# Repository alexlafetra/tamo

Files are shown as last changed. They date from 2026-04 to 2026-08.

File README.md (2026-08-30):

# Tamo

Tamo is an open source interdisciplinary hardware project designed to be both a piece of jewelry and a small being with (somewhat) complex emotions. This repository contains the firmware, hardware design (PCB & 3D files), graphics, and code for the web tools for sprite design and custom creature upload.

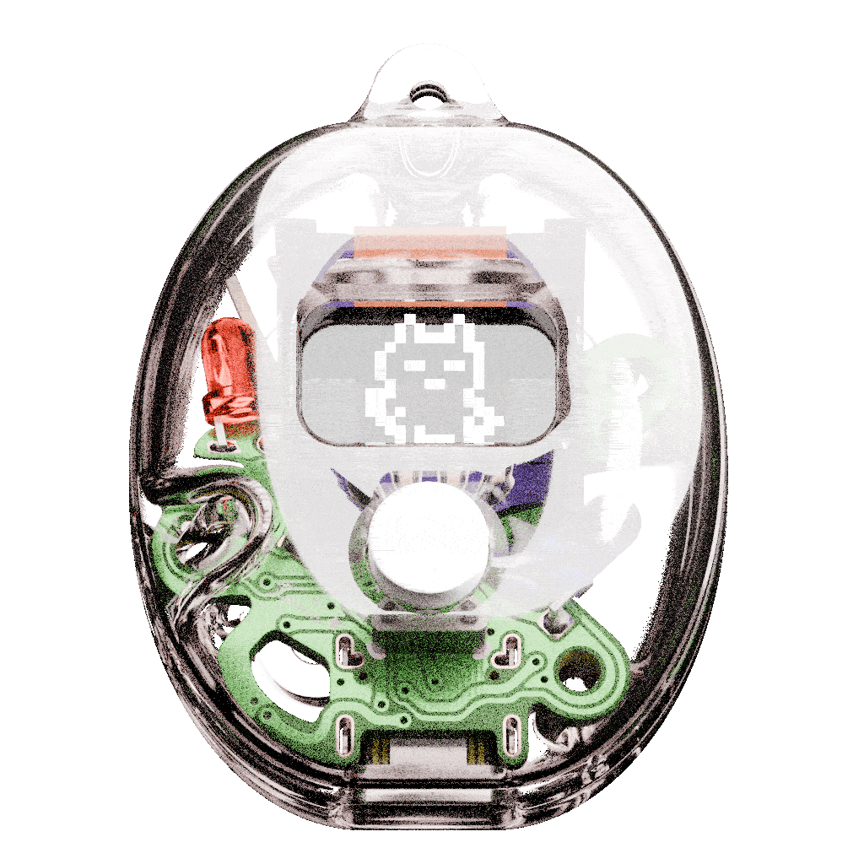
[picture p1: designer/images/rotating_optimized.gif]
gif of tamo rotating


### Background

This project started as a way of making something that could be shared between people in my life that felt precious, but also mass-produced. It's designed to feel like it has an independent existence outside of just being your pet, like maybe it's "going through some shit," but also like you can effectively comfort it and have a connection to the creature inside Tamo.

### Modes

Tamo supports two modes: the default, "alive" mode and an "animation" mode: 

###### Animation
The animation mode is a very simple video player or slideshow which can loop over up to 16 frames of video at different speeds. It's designed more for tamo as a piece of jewelry, and doesn't feature any interaction other than turning tamo on/off with the main button.

###### Living
Living mode is the default mode for Tamo. While living, Tamo ages, speaks, gets hungry, gets happy, gets sad, gets angry, and eventually dies. Tamo can be afflicted by different maladies: a smoking habit, compulsive eating, mood swings, and depression. Tamo can be fed, talked to, or connected to another Tamo to swap places.

# Sprites
The [custom sprite designer](https://alexlafetra.github.io/tamo/designer.html?sprite) is a tool for creating animations & sprite art for tamo, which can be uploaded to the device using the browser and a USB-C cable.

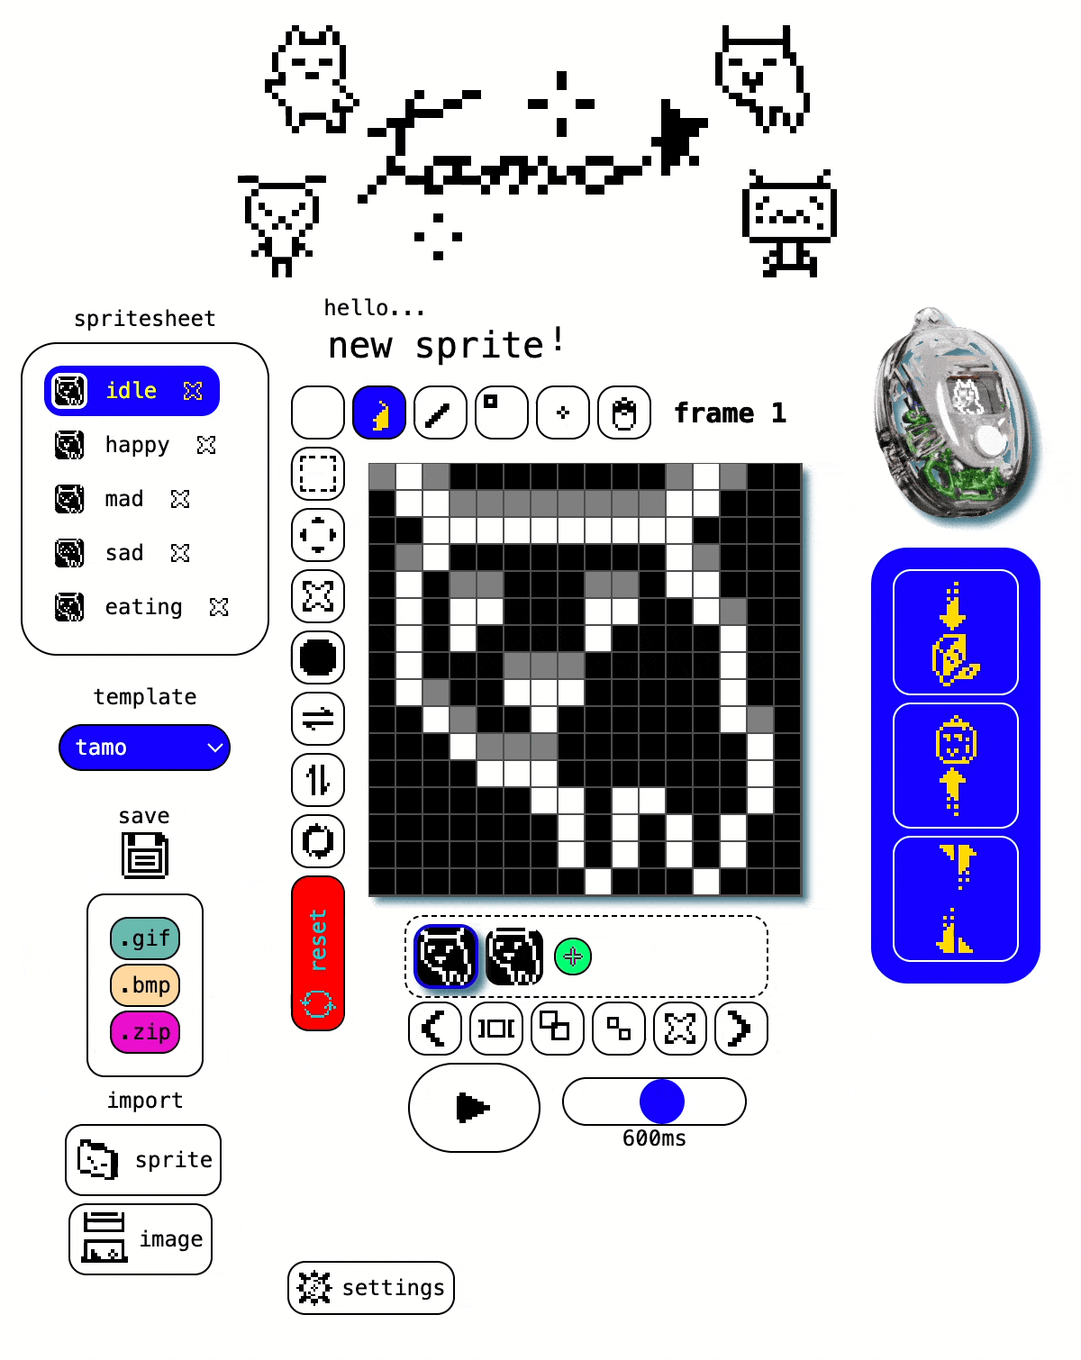
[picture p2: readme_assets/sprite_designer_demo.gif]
screenshot of the designer ui


The mode & creature identity can be set, and new sprites can be flashed to Tamo over USB, using [Tamo's website](https://alexlafetra.github.io/tamo/).

# Firmware

Tamo's firmware is a PlatformIO project built around Spence Konde's [megaTinyCore](https://github.com/SpenceKonde/megaTinyCore) and the Arduino framework, with a modified build process to allow for in-system flash reprogramming. This project uses [PlatformIO](https://platformio.org/) for compiling with a [custom linker script](/tamo/linker/sprites.ld) and to run a few python scripts that upload the EEPROM and custom fuses to the Attiny. Unfortunately, this project hasn't been ported to work as a standalone Arduino project, but this repository contains all the libraries and the platformio.ini file needed to setup the platformIO environment, hopefully making use of the platformIO extension for VSCode almost as beginner-friendly.

During compilation, a python script--`/scripts/compile_spritesheet.py`--automatically converts selected `.bmp` files inside the `/bitmaps` folder to C++ byte arrays and appends them to the main spritesheet array. The creature sprites selected by this script are randomly chosen each time from the 7 default creatures, so each tamo gets a different mix of sprite artwork to start with. Each of these creatures can be overwritten later, though.

A second script--`/scripts/build_eeprom.py`--builds a binary file with the default EEPROM values and writes it to the Attiny3217's EEPROM memory after the firmware upload.

## Uploading firmware

The Attiny3217 firmware is uploaded via its UPDI interface, which is exposed on the motherboard as three header pins (UPDI,GND, and VCC). For development, I've been using [pymcuprog](https://pypi.org/project/pymcuprog/) and this [Pico UART Bridge](https://github.com/Noltari/pico-uart-bridge) design to use a Pi Pico as a UPDI programmer and upload code to the Attiny. Any USB UPDI programmer should work, though!

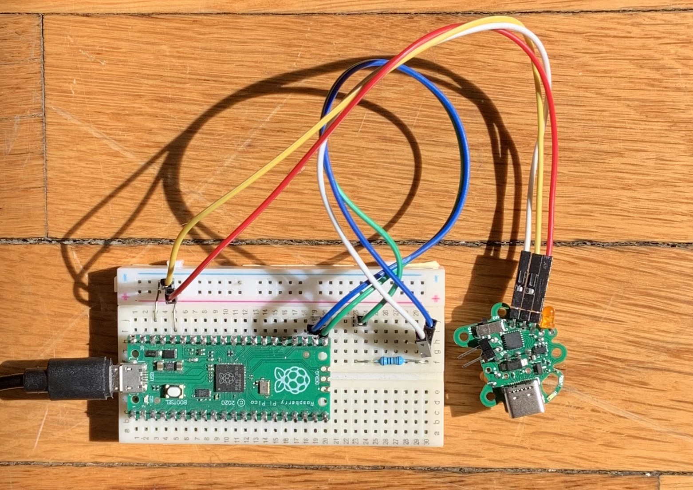
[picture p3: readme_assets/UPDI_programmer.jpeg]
Image of Tamo with UPDI programmer

###### Example of the Pico UART Bridge wired to the Tamo board's UPDI header pins as a programmer.

Although the UPDI headers are exposed on the board, the `SBU1/SBU2` pins on Tamo's USB-C jack are also both tied to the UPDI pin on the Attiny so the chip can be programmed using just a USB cable plugged into the USB-C port with the other end specially wired to a UPDI programmer. You'll need to make sure whatever cable you use for this carries the `SBU1/SBU2` lines, but this allows programming Tamo from inside its shell.

### A note about custom fuses & overwriteable flash

The Attiny has strict rules about which sections of flash memory can overwrite other sections -- code running in `BOOT` can overwrite `APPCODE` and `APPDATA` sections, but `BOOT` can never be overwritten (even by other code running from `BOOT`). By default, the *entire* memory of the Attiny is designated as the `BOOT` section, meaning the code uploaded to flash doesn't have permission to rewrite any part of the Attiny's memory.

So, to overwrite bitmap data during runtime (allowing the firmware to overwrite new artwork in the Attiny's flash without recompiling the firmware with new sprites) we need to ask the Attiny3217 to store the bitmap data in a section of its memory demarcated as `APPCODE` while still running the main code from the `BOOT` section. This just requires three things:

1. Creating a linker script which places the `spritesheet` variable containing all the bitmap data at a fixed memory address. This linker script is a copy of the default TinyMegaCore linker script, with a special section titled ".bitmap_data" added which has a specific, fixed address. 

2. The "spritesheet" variable in our C++ code needs a little linker flag to tell the linker to place it in that new ".bitmap_data" section:

```
const unsigned char spritesheet[]  __attribute__((section(".bitmap_data"))) = {
    ... DATA ...
};

```

2. Finally, the `BOOTEND` and `APPEND` fuses on the Attiny3217 need to be set during upload so that the `BOOT`/`APPCODE` partition is created, at the specific address of .bitmap_data, so that the .bitmap_data section is placed in `APPCODE`.

The addresses are written as `[APPEND page address, BOOTEND page address]` (the addresses values are actually the 256-byte *page* address, ie. 0x01 is byte 256, 0x02 is byte 512 etc.) For tamo, the `BOOTEND` fuse is set to `0x5E = 94`, meaning `94 x 256B = 24,064B` of flash is reserved for the main firmware running in `BOOT`, and the remaining ~8kB are used for bitmaps. The `APPEND` fuse is set to `0x00`, which tells the Attiny3217 to allocate the rest of flash from `BOOTEND` onwards for the `APPCODE` section.

To set these fuses using `pymcuprog`, run:

```
pymcuprog write --tool uart --device attiny3217 --uart {USB DEVICE PORT} --clk 230400 --memory fuses --offset 7 --literal 0x00 0x5E 
```
###### On Mac: The USB device will be something like ```/dev/cu.usbmodem14101```. Run ```ls /dev/tty.*``` in a terminal window to get a list of connected USB devices.

To read back the fuse values and check if they were written correctly, run:

```
pymcuprog read --tool uart --device attiny3217 --uart {USB DEVICE PORT} --clk 230400 --memory fuses
```

## Thank you's

This project is built with support from these other projects:

- [pymcuprog](https://pypi.org/project/pymcuprog/), for uploading and writing fuses via UPDI

- This [Pico UART Bridge](https://github.com/Noltari/pico-uart-bridge) project for building a custom UPDI programmer, so helpful!

- The code for the display was originally based on Datacute's [SSD1306 OLED Library](https://github.com/datacute/Tiny4kOLED), although now very heavily augmented

- The PCBs for this project were designed in [KiCad](https://www.kicad.org/) and specifically the battery charging schematic is based on the schematic for Adafruit's [MicroLipo Battery Charger](https://github.com/adafruit/Adafruit-MicroLipo-PCB)

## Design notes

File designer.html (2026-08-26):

v1.0.0

tamo sprite designer

[ pixel editing ]

+ [shift] - toggle color

+ p - pixel

+ l - line

+ r - rectangle

+ c - circle

+ f - fill

[ frame editing ]

+ s - select

+ m - move

[ misc. ]

+ [space] - play/pause

+ [ < / > ] - change frame

+ [ ^ / v ] - change sprite

canvas

grid

overlay

*

resize

-- zoom --

 settings

download spritesheet

{Y}

automatically create sprites

resize canvas to images

show debug transmission buttons

show canvas settings

--foreground--

white

black

transparent

--background--

white

black

transparent

copy

image





dither:







brightness:

resize to fit:

width

height

center

save



.gif

.bmp

.zip

import



sprite



image











animation



--speed--

1fps

--sleep--

5min

--blink--

off

spritesheet

template

hello...

new sprite

!















600ms















pixel















 reset

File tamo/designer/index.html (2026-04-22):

    



frame -- 1 / 1













undo

redo

pixel













invert







settings

x

frame delay

zoom

hide grid

disable overlay

sprites:

template:

 upload

export to tamo

save...

.zip

.gif

name:

tamo

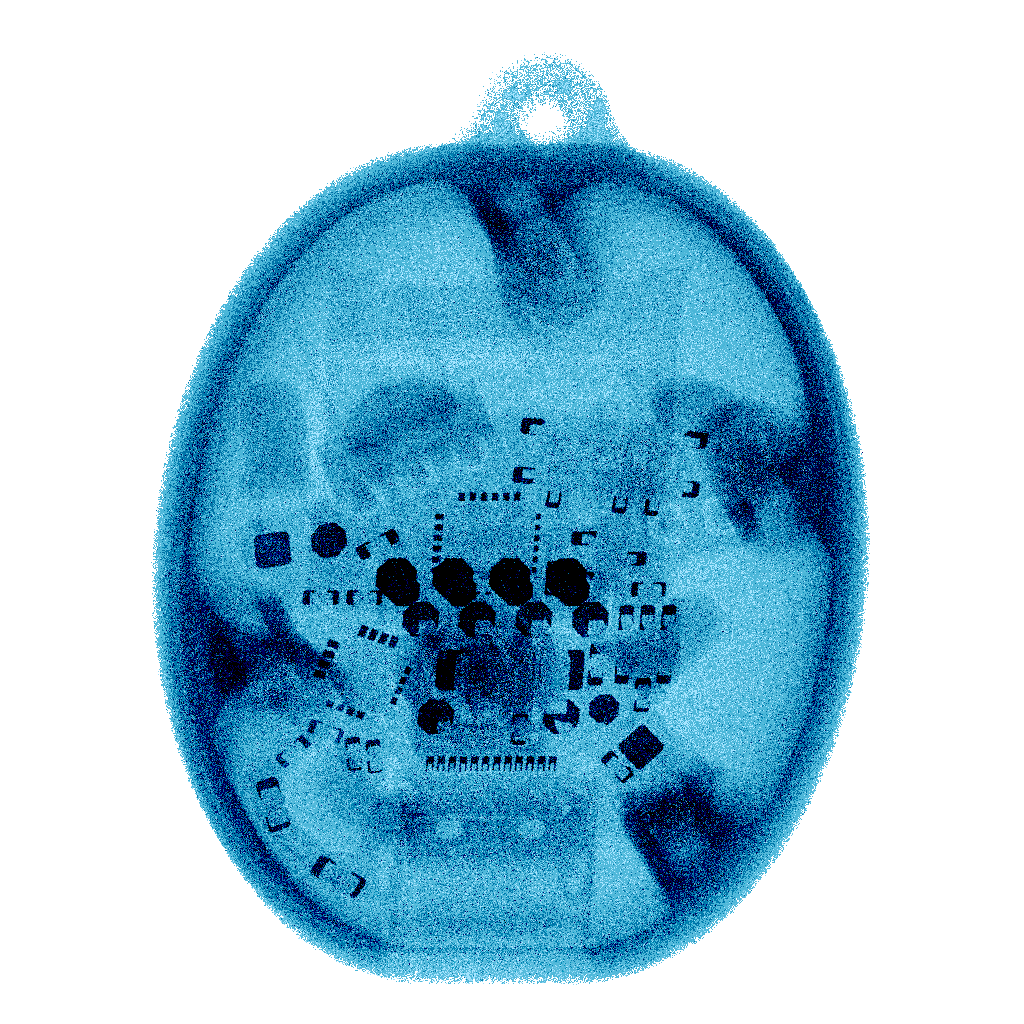
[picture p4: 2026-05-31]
designer/images/combined_optimized.gif

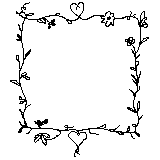
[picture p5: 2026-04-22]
designer/images/border_animated.gif

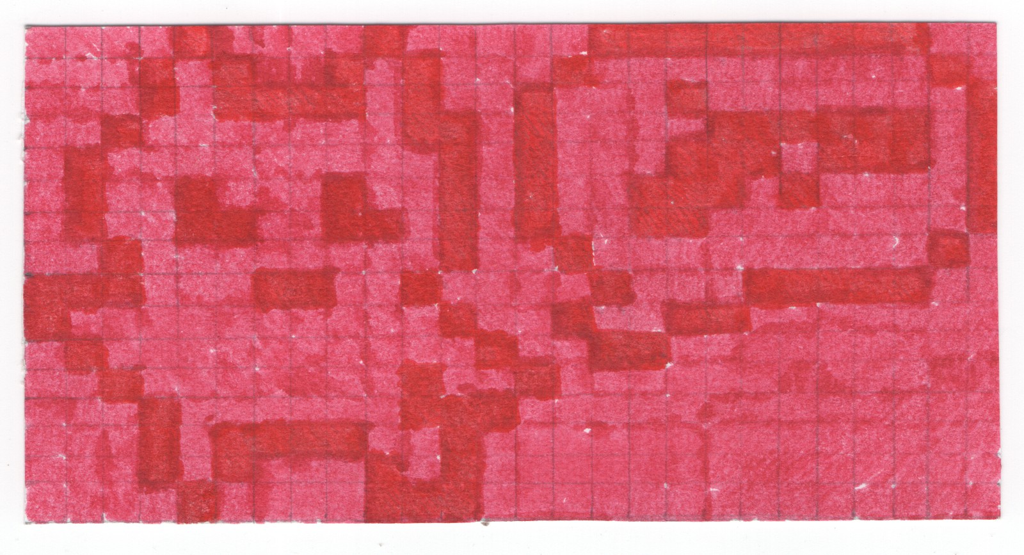
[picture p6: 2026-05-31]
designer/images/tamo_drawing.jpg

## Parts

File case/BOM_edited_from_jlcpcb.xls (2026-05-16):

JLCPCB BOM Tool - BOM Matching
BOM name：bom-JLCPCB Assembly Order.xlsx |  |  | Download Time：2026-02-26 04:10:01 |  |  |  | * Our matching results are updated in real-time, but stock and prices may change. If it's been over 24 hours, please re-match before placing your order.
PCB Assembled Qty：5 |  |  | Est. Total Price：18.4623
Your BOM |  |  |  |  | Matched Parts |  |  |  |  |  |  | Order Information
Top Designator | Bottom Designator | Comment | Footprint | JLCPCB Part # | Matches | Part # | Manufacturer | Footprint | Description | Category | Warning | JLCPCB Part # | Product link | Lib Type | Qty | Source | Total Price ($)
 | C2,C1 | 10碌F | C_0402_1005Metric |  | Select by System | CL05A106MQ5NUNC | Samsung Electro-Mechanics | 0402 | 10uF 6.3V X5R ±20% 0402 Multilayer Ceramic Capacitors MLCC - SMD/SMT ROHS | Multilayer Ceramic Capacitors MLCC - SMD/SMT |  | C15525 | https://jlcpcb.com/partdetail/16204-CL05A106MQ5NUNC/C15525 | Basic | 10 | 10 JLCPCB | 0.056
 | D3 | LED | LED_0603_1608Metric |  | Select by System | KT-0603R | Hubei KENTO Elec | 0603 | -40℃~+85℃ 120° 2.4V 20mA 300mcd 40mW 615nm~630nm 645nm Discrete Diode Red Water Clear 0603 LED Indication - Discrete ROHS | LED Indication - Discrete |  | C2286 | https://jlcpcb.com/partdetail/Hubei_KENTOElec-KT0603R/C2286 | Basic | 5 | 5 JLCPCB | 0.0325
 | D4 | LED | LED_0603_1608Metric |  | Select by System | KT-0603W | Hubei KENTO Elec | 0603 | 100mW 120° 2.6V~3.1V 360mcd 5mA Discrete Diode Top-mount White Yellow Lens 0603 LED Indication - Discrete ROHS | LED Indication - Discrete |  | C2290 | https://jlcpcb.com/partdetail/Hubei_KENTOElec-KT0603W/C2290 | Basic | 5 | 5 JLCPCB | 0.059
 | D5 | SS14 | D_SMA |  | Select by System | SS14 | MDD(Microdiode Semiconductor) | SMA(DO-214AC) | -55℃~+150℃ 1A 25A 300uA@40V 40V 550mV@1A Independent SMA(DO-214AC) Schottky Diodes ROHS | Schottky Diodes |  | C2480 | https://jlcpcb.com/partdetail/MDD_Microdiode_Semiconductor-SS14/C2480 | Basic | 5 | 5 JLCPCB | 0.0825
 | J4 | USB_C_Receptacle | USB_C_Receptacle_24P_TopMnt_Horizontal |  | Select by System | MC-312D-C | SOFNG | SMD | -35℃~+75℃ 1 12V 24P 5A 7.9mm 8,000 times、10,000 cycles Black Female Surface Mount, Right Angle Type-C SMD USB Connectors ROHS | USB Connectors |  | C183607 | https://jlcpcb.com/partdetail/SOFNG-MC_312DC/C183607 | Extended | 5 | 5 JLCPCB | 2.8715
 | Q1 | BSS83P | SOT-23 |  | Select by System | SI2301CDS-T1-GE3 | Vishay Intertech | SOT-23 | -55℃~+150℃ 1 P-Channel 1.6W 10nC@4.5V 142mΩ@2.5V 1V 20V 3.1A 405pF 55pF 75pF P-Channel SOT-23 MOSFETs ROHS | MOSFETs |  | C10487 | https://jlcpcb.com/partdetail/VishayIntertech-SI2301CDS_T1GE3/C10487 | Basic | 5 | 5 JLCPCB | 0.3
 | R2,R3 | 470 | R_0402_1005Metric |  | Select by System | 0402WGF4700TCE | UNI-ROYAL(Uniroyal Elec) | 0402 | -55℃~+155℃ 470Ω 50V 62.5mW Thick Film Resistor ±1% ±100ppm/℃ 0402 Chip Resistor - Surface Mount ROHS | Chip Resistor - Surface Mount |  | C25117 | https://jlcpcb.com/partdetail/25860-0402WGF4700TCE/C25117 | Basic | 10 | 10 JLCPCB | 0.008
 | R5 | 4.7k | R_0402_1005Metric |  | Select by System | 0402WGF4701TCE | UNI-ROYAL(Uniroyal Elec) | 0402 | -55℃~+155℃ 4.7kΩ 50V 62.5mW Thick Film Resistor ±1% ±100ppm/℃ 0402 Chip Resistor - Surface Mount ROHS | Chip Resistor - Surface Mount |  | C25900 | https://jlcpcb.com/partdetail/26643-0402WGF4701TCE/C25900 | Basic | 5 | 5 JLCPCB | 0.004
 | R6 | 10K | R_0402_1005Metric |  | Select by Customer | 0402WGF1002TCE | UNI-ROYAL(Uniroyal Elec) | 0402 | -55℃~+155℃ 10kΩ 50V 62.5mW Thick Film Resistor ±1% ±100ppm/℃ 0402 Chip Resistor - Surface Mount ROHS | Chip Resistor - Surface Mount |  | C25744 | https://jlcpcb.com/partdetail/26487-0402WGF1002TCE/C25744 | Basic | 5 | 5 JLCPCB | 0.004
 | R7 | 33K | R_0402_1005Metric |  | Select by System | 0402WGF3302TCE | UNI-ROYAL(Uniroyal Elec) | 0402 | -55℃~+155℃ 33kΩ 50V 62.5mW Thick Film Resistor ±1% ±100ppm/℃ 0402 Chip Resistor - Surface Mount ROHS | Chip Resistor - Surface Mount |  | C25779 | https://jlcpcb.com/partdetail/26522-0402WGF3302TCE/C25779 | Basic | 5 | 5 JLCPCB | 0.004
 | R1A1,R2A1,R1,R4 | 5.1K | R_0402_1005Metric |  | Select by Customer | 0402WGF5101TCE | UNI-ROYAL(Uniroyal Elec) | 0402 | -55℃~+155℃ 5.1kΩ 50V 62.5mW Thick Film Resistor ±1% ±100ppm/℃ 0402 Chip Resistor - Surface Mount ROHS | Chip Resistor - Surface Mount | 1.There may be multiple types of parts, but one type of part has been matched. Please check.; | C25905 | https://jlcpcb.com/partdetail/26648-0402WGF5101TCE/C25905 | Basic | 20 | 20 JLCPCB | 0.016
 | U3 | ~ | SMD,8x2.8mm |  | Select by System | MSK12C02-HB | SHOU HAN | SMD,8x2.8mm | -25℃~+70℃ 1.4mm 10,000 Cycles 12V 2.8mm 50mA 8mm Black Rectangular Columnar SMD(SMT) Tab SPDT Surface Mount, Right Angle SMD,8x2.8mm Slide Switches ROHS | Slide Switches |  | C431541 | https://jlcpcb.com/partdetail/SHOUHAN-MSK12C02HB/C431541 | Extended | 6 | 6 JLCPCB | 0.3678
 | U4 | MCP73831T-2ACI/OT | SOT-23-5 |  | Select by System | MCP73831T-2ACI/OT | Microchip Tech | SOT-23-5 | -40℃~+85℃ 1 3.75V~6V 4.2V 53uA 550mA Charging IC Lithium Battery SOT-23-5 Battery Management ROHS | Battery Management |  | C424093 | https://jlcpcb.com/partdetail/MicrochipTech-MCP73831T_2ACIOT/C424093 | Extended | 5 | 5 JLCPCB | 3.6645
 | U6 | ATtiny3217-M | QFN-24-1EP_4x4mm_P0.5mm_EP2.6x2.6mm |  | Select by System | ATTINY3217-MNR | Microchip Tech | WQFN-24-EP(4x4) | -40℃~+105℃ 1.8V~5.5V 10bit 20MHz 22 256Byte 2KB 32KB 8 Bit 8bit AVR Built-in FLASH WQFN-24-EP(4x4) Microcontrollers (MCU/MPU/SOC) ROHS | Microcontrollers (MCU/MPU/SOC) |  | C614177 | https://jlcpcb.com/partdetail/MicrochipTech-ATTINY3217MNR/C614177 | Extended | 5 | 5 JLCPCB | 10.9925

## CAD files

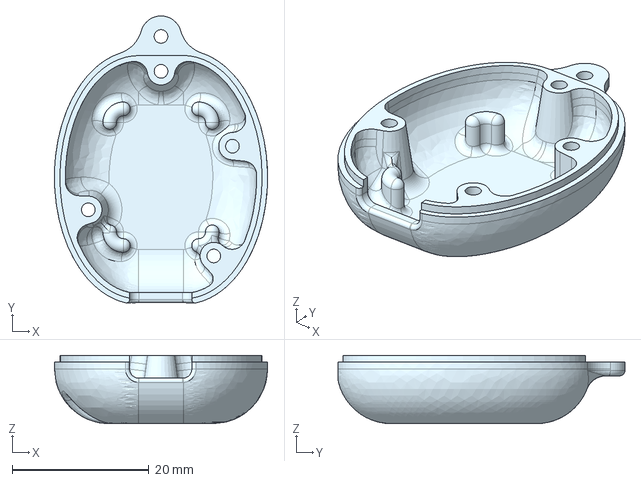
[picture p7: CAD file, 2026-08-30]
case/bottom.step
31.2 x 42.0 x 10.0 mm

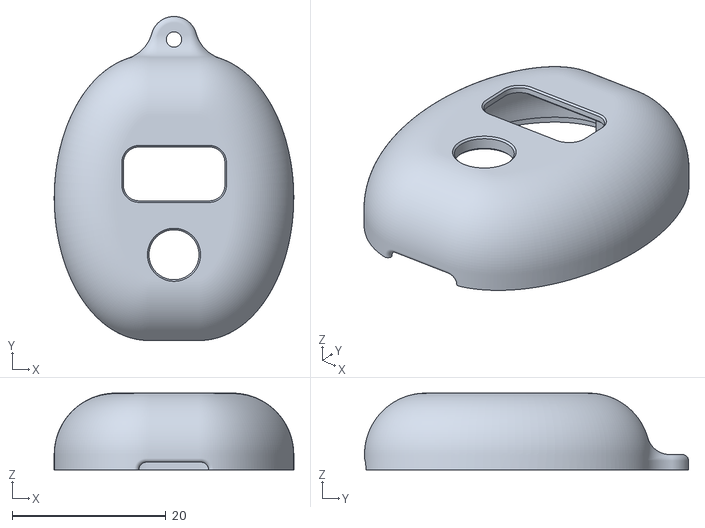
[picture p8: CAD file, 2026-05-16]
case/top.stl
31.2 x 42.2 x 10.0

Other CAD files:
case/TOP_SHELL_12.23.25.stl

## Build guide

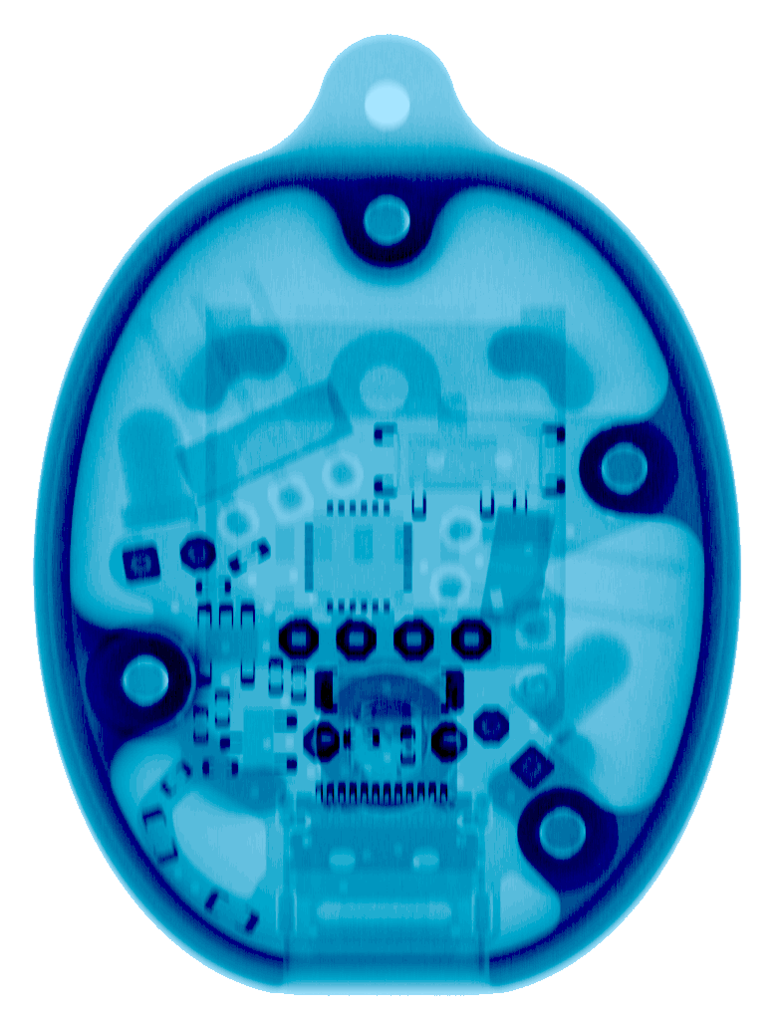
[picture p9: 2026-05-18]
manual/images/xray_alpha.png

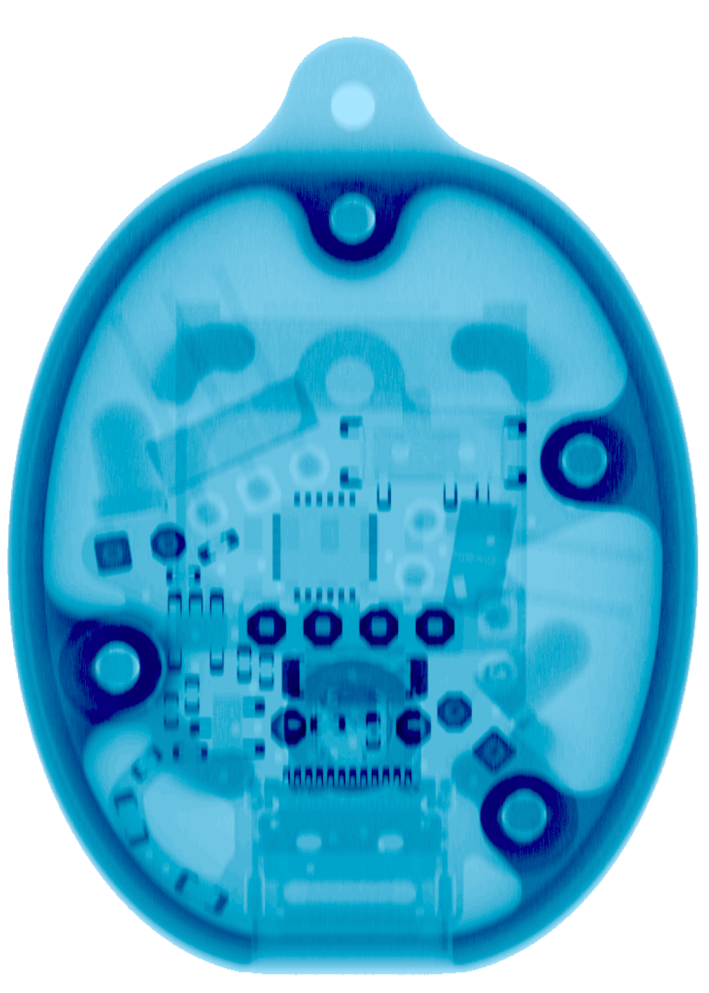
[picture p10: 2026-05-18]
manual/images/xray.png

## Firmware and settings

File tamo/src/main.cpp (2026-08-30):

//https://github.com/Lorandil/ATTiny85-optimization-guide?tab=readme-ov-file

//pi pico UART bridge for programming:
//https://github.com/Noltari/pico-uart-bridge

// GPIO16 (Pin 21)	UART0 TX
// GPIO17 (Pin 22)	UART0 RX
// GPIO4 (Pin 6)	UART1 TX
// GPIO5 (Pin 7)	UART1 RX

/*

ok some really convoluded upload stuff:
burning fuses/bootloader needs to be done with UDPI?
CLOCK needs to be 10MHz to communicate with arduino IDE, dunno why

SUPER annoying highkey annoying vibes
 --> flashing fuses/initial upload needs to use UPDI friend (dunno why it won't work with pi pico)
 --> Subsequent UART uploads need to be done within 8s of a power cycle, which means plug/unplug attiny (or connect a lil button)
 ^^THIS is important for the new board designs, bc the user shouldn't have to power cycle the board!
 ==> Test w the 1sec timeout and see if that works. Figure out how to "Reset"/power cycle Attiny via the USB-->UART bridge
 ^^Actually, i guess this isn't important for the board design since you don't need to "enter bootloader" unless you're actually
 uploading new code, at which point yeah you'll need to reset the tamo
*/


#define BUTTON_PIN PIN_PA2
#define LED_1 PIN_PA6
#define LED_0 PIN_PC0
#define UART_RX_PIN PIN_PB3
#define UART_TX_PIN PIN_PB2


/*
notes on pins:

PA7 -- Battery vcc

PB0 -- screen SCL
PB1 -- screen SDA

PB2 -- UART TX
PB3 -- UART RX

PA6 -- DAC out / LED A
PC0 -- LED B
*/

using namespace std;

#include <EEPROM.h>
#include "utils.h"
#include "communication.h"
#include "spritesheet.h"

//this stores the active graphics area! which is half-res of the screen, sprites are drawn 2x
#include "FrameBuffer.h"
// FrameBuffer fbo(36,24);

#include <Wire.h>
#include "Display.h"
SSD1306Device oled;

#include "Tamo.h"
Tamo tamo;

// FrameBuffer fbo(72,48);
// FrameBuffer fbo(36,24);
/*
the attiny3217 can't store a full 64x32 buffer in RAM, so instead
you store a half-buffer, which is good enough for almost everything
except full-screen slideshow images.
These need to be split into two 64x16 chunks
*/
FrameBuffer fbo(32,32);



//Interrupt callback to wake Attiny back up
ISR(PORTA_PORT_vect) {
  PORTA.INTFLAGS = PIN2_bm; // Clear interrupt flag for PIN 2
  tamo.setStatusBit(IS_ASLEEP_BIT,false);
}

//RTC 'body()' timer interrupt to update tamo's health/state
//taken from: https://github.com/SpenceKonde/megaTinyCore/blob/master/megaavr/extras/PowerSave.md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
ISR(RTC_PIT_vect)
{
  RTC.PITINTFLAGS = RTC_PI_bm;          /* Clear interrupt flag by writing '1' (required) */
  tamo.body();
}

//initialize RTC
//also taken from: https://github.com/SpenceKonde/megaTinyCore/blob/master/megaavr/extras/PowerSave.md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
void RTC_init(void)
{
  /* Initialize RTC: */
  while (RTC.STATUS > 0)
  {
    ;                                   /* Wait for all register to be synchronized */
  }
  RTC.CLKSEL = RTC_CLKSEL_INT32K_gc;    /* 32.768kHz Internal Ultra-Low-Power Oscillator (OSCULP32K) */

  RTC.PITINTCTRL = RTC_PI_bm;           /* PIT Interrupt: enabled */

  // RTC.PITCTRLA = RTC_PERIOD_CYC16384_gc /* RTC Clock Cycles 16384, resulting in 32.768kHz/16384 = 2Hz */
  RTC.PITCTRLA = RTC_PERIOD_CYC32768_gc /* RTC Clock Cycles 16384, resulting in 32.768kHz/16384 = 2Hz */
  | RTC_PITEN_bm;                       /* Enable PIT counter: enabled */
}

//important to do so you save power on sleep()
void disconnectUnusedPins(){
  const uint8_t unused_pins[] = {
    //updi pin, doesn't need to be disconnected
    // PIN_PA0,
    PIN_PA1,
    // PIN_PA2, //Button
    PIN_PA3,
    PIN_PA4,
    PIN_PA5,
    // PIN_PA6, //LED A
    PIN_PA7,
    // PIN_PB0, //SCL
    // PIN_PB1, //SDA
    // PIN_PB2, //RX
    // PIN_PB3, //TX
    PIN_PB4,
    PIN_PB5,
    PIN_PB6,
    PIN_PB7,
    // PIN_PC0, //LED B
    PIN_PC1,
    PIN_PC2,
    PIN_PC3,
    PIN_PC4,
    PIN_PC5
  };
  for(uint8_t i = 0; i<sizeof(unused_pins); i++){
    pinMode(unused_pins[i],OUTPUT);
  }
}

//trying to set the IVSEL register, so the vectors are placed in BOOT instead of APPCODE
//which happens automatically when BOOT isn't 0x00
//src: https://www.microchip.com/content/dam/mchp/documents/OTH/ApplicationNotes/ApplicationNotes/AN1983WritingtoFlashandEEPROMonthetinyAVR1-series40001983A.pdf
//sec 2.2
void onBeforeInit(){
  CCP = CCP_IOREG_gc;           // unlock protected register, 4-cycle window
  CPUINT.CTRLA = CPUINT_IVSEL_bm; // set IVSEL=1: vectors at start of BOOT (0x0000)
}

void setup(){

  //connect pins to leds, button
  pinMode(LED_1,OUTPUT);
  pinMode(LED_0,OUTPUT);
  pinMode(BUTTON_PIN,INPUT_PULLUP);

  //set floating pins to OUTPUT (to save power during sleep)
  disconnectUnusedPins();

  //this sleep mode only leaves the RTC running, and it's the one that saves the most energy
  set_sleep_mode(SLEEP_MODE_PWR_DOWN);
  
  //allows the CPU to go to sleep
  sleep_enable();

  // Enable global interrupts
  sei();

  //turn on RTC timer
  RTC_init();

  //turn on/set up the screen
  oled.begin(72, 40);
  
  //initialize UART
  Serial.begin(115200);

  tamo.init();
}

void loop() {
  // tamo.qrCode();
  switch(tamo.mode){
    default:
    case NORMAL_TAMO:
      tamo.live();
      break;
    case SLIDESHOW:
      tamo.slideshow();
      break;
  }
}

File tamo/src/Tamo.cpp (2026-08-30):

#include "Arduino.h"
#include "Sprite.h"
#include "Tamo.h"
#include "utils.h"
#include "Display.h"
#include "spriteFrames.h"
#include "communication.h"
#include <EEPROM.h>

Tamo::Tamo(){
  sprite = Sprite(SPRITESTARTX,SPRITESTARTY,16,16,getSprite(IDLE_SPRITE),2,MEDIUM);
}

void Tamo::init(){
  mode = TAMO_MODE(EEPROM.read(EEPROM_MODE_ADDR));
  identity = SPRITE_IDENTITY(EEPROM.read(EEPROM_IDENTITY_ADDR));
  health = uint16_t(EEPROM.read(EEPROM_HEALTH_ADDR_MSB))<<8 | uint16_t(EEPROM.read(EEPROM_HEALTH_ADDR_LSB));
  // status = EEPROM.read(EEPROM_STATUS_ADDR); //this is causing weird problems with sleep, smoking on reboot
  setStatusBit(NEEDS_TO_SMOKE_BIT,false);
}

bool Tamo::getStatusBit(uint8_t which){
  return 1&(status>>which);
}

void Tamo::setStatusBit(uint8_t which, bool state){
  if(state){
    status |= (1<<which);
  } 
  else{
    status &= ~(1<<which);
  }
}

void Tamo::sleepCheck(){
  setStatusBit(IS_ASLEEP_BIT,itsbeen(TIME_BEFORE_SLEEP));
}

void Tamo::sleep(){

  //set tamo into sleep mode
  setStatusBit(IS_ASLEEP_BIT,true);

  //when the RTC interrupt finishes it goes to this line and tamo can go back to sleep
  while(isAsleep()){
    // digitalWrite(LED_1,CHANGE);
    //put the attiny to sleep
    sleepHardware();
  }

  wakeHardware();
}

void Tamo::setIdentity(SPRITE_IDENTITY i){
  EEPROM.update(EEPROM_IDENTITY_ADDR,i);
  identity = i;
  setMoodSprite();
}

const uint16_t * Tamo::getSprite(uint8_t whichSprite){
  return creature_sprites[identity][whichSprite];
  // switch(identity){
  //   case TAMO:
  //     return tamo_spritesheet[whichSprite];
  //   case PORCINI:
  //     return porcini_spritesheet[whichSprite];
  //   case BUG:
  //     return bug_spritesheet[whichSprite];
  //   case BOTO:
  //     return boto_spritesheet[whichSprite];
  //   case CUSTOM_SPRITE:
  //     return custom_spritesheet[whichSprite];
  //   default:
  //     return tamo_spritesheet[whichSprite];
  // }
}

void Tamo::slideshow(){

  //preset speeds/sleep times (0 sleep time is infinite)
  const uint16_t slideshow_speeds[] = {0,100,500,1000,2000,5000,10000,60000};
  const uint32_t slideshow_sleep_times[] = {0,10000,60000,300000};

  uint8_t slideshow_framecount = EEPROM.read(EEPROM_SLIDESHOW_FRAME_COUNT_ADDR);
  uint16_t slideshow_speed = slideshow_speeds[EEPROM.read(EEPROM_SLIDESHOW_SPEED_ADDR)];
  uint32_t slideshow_sleeptime = slideshow_sleep_times[EEPROM.read(EEPROM_SLIDESHOW_SLEEP_TIME_ADDR)];
  uint16_t slideshow_blink_interval = EEPROM.read(EEPROM_SLIDESHOW_BLINK_TIME_ADDR);
  
  if(slideshow_blink_interval == 0)
    oled.disableFadeOutAndBlinking();
  else
    oled.blink(slideshow_blink_interval-1);

  uint32_t timeOfLastFrame = 0;
  uint8_t counter = 0;

  //offset LEDs so they're opposite
  digitalWrite(LED_1,LOW);
  digitalWrite(LED_0,HIGH);

  LONG_PRESS = false;
  lastTime = millis();

  while(true){
    timeOfLastFrame = millis();
    oled.bitmap_from_spritesheet(4,0,64,32,slideshow_frame_0+counter*256);

    counter = (counter+1)%slideshow_framecount;

    //if the speed is slow, change LEDs on each frame
    if(slideshow_speed > 100){
      digitalWrite(LED_1,CHANGE);
      digitalWrite(LED_0,CHANGE);
    }
    //if it's fast, change LEDs when frames wrap around
    else if(counter == 0){
      digitalWrite(LED_1,CHANGE);
      digitalWrite(LED_0,CHANGE);
    }

    do{
      checkInput(false);
      //the itsbeen(500) call is for debouncing
      if((SINGLE_CLICK && itsbeen(500)) || ((slideshow_sleeptime == 0)?false:itsbeen(slideshow_sleeptime))){
        sleep();
        lastTime = millis();
        timeOfLastFrame = millis();
        digitalWrite(LED_1,LOW);
        digitalWrite(LED_0,HIGH);
      }
      if(LONG_PRESS && itsbeen(1000)){
        EEPROM.update(EEPROM_MODE_ADDR,NORMAL_TAMO);
        mode = NORMAL_TAMO;
        return;
      }
    }
    while(((millis() - timeOfLastFrame) < slideshow_speed));
  }
}

void Tamo::qrCode(){
  lastTime = millis();
  digitalWrite(LED_1,HIGH);
  digitalWrite(LED_0,LOW);
  uint32_t ledTime = millis();
  oled.clear();
  while(true){
    // oled.bitmap_from_spritesheet(22,0,25,25,qr_code);
    oled.bitmap_from_spritesheet(4,0,25,25,qr_code);
    oled.bitmap_from_spritesheet(41,0,25,25,qr_code);
    if(itsbeen(1000)){
      checkInput(false);
      if(SINGLE_CLICK)
        break;
    }
    if((millis() - ledTime) > 1000){
      digitalWrite(LED_1,CHANGE);
      digitalWrite(LED_0,CHANGE);
      ledTime = millis();
    }
  }
  oled.clear();
  digitalWrite(LED_1,LOW);
  digitalWrite(LED_0,LOW);
  mood = MOOD_RANDOM;
}

bool Tamo::isFeeling(){
  //if there's still time on the moodTime counter, or if there's not but the next frame isn't yet, keep animating
  //over ride this if tamo dies!
  return ((moodTime>0 || !(sprite.isNextFrameReady() && sprite.hasPlayedAtLeastOnce())) && !getStatusBit(IS_DEAD_BIT));
}

// update function that runs on a timer interrupt every 1s
void Tamo::body(){

  if(mode != NORMAL_TAMO)
    return;

  if(mood ==  MOOD_BIRTH || mood == MOOD_DEAD)
    return;

  timeSinceLastCig++;
  //tamo only smokes if it's asleep, not dead, and not being born, since smoking can change tamo's mood
  if(timeSinceLastCig > 600 && isAsleep() &&  !getStatusBit(IS_DEAD_BIT)){
    mood = MOOD_SMOKING;
    setStatusBit(IS_ASLEEP_BIT,false);
    setStatusBit(NEEDS_TO_SMOKE_BIT,true);
    timeSinceLastCig = 0;
    return;
  }
  // if(isAsleep() &&  !getStatusBit(IS_DEAD_BIT) && randomInt(240)){
  //   mood = MOOD_PECKISH;
  //   setStatusBit(IS_ASLEEP_BIT,false);
  //   return;
  // }
  

  uint8_t healthLoss = 0;
  if(hunger < 65535)
    hunger++;
  
  //hunger hits 28800 every 8 hrs
  if(hunger > 28800){
    //you loose health half as quickly for the first 8 hrs of being hungry
    if(hunger < 57600){
      if(hunger%2)
        healthLoss = HEALTH_LOSS;
    }
    //then u lose 1h/s
    else{
      healthLoss = HEALTH_LOSS;
    }
  }
  //if pooping, you also lose health (this compounds)
  if(mood == MOOD_POOPING){
    healthLoss += HEALTH_LOSS;
  }

  //update health
  health = (health < healthLoss) ? 0:(health - healthLoss);
  //if tamo dies, set the death bit which is detected in vibecheck()
  setStatusBit(IS_DEAD_BIT,health == 0);

  //update EEPROM
  //eeprom has 100k write cycles, 1 write/two hours ==> 23yrs
  updatesSinceLastEEPROMSave++;
  if(updatesSinceLastEEPROMSave >= 7200){
    updatesSinceLastEEPROMSave = 0;
    EEPROM.update(EEPROM_HEALTH_ADDR_MSB,health>>8);
    EEPROM.update(EEPROM_HEALTH_ADDR_LSB,health&255);
    EEPROM.update(EEPROM_STATUS_ADDR,status);
  }
}
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

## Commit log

2024-07-26 Uhh... okay
    mood cycle is now less buggy and easier to change, interrupt from sleep works correctly, oled screen clearing is quicker, sprite updates, new thoughts, no glitchy sprites (so far!)
    [Animation.h, Tamo.h]
2024-07-31 added 3d files, pcb files
    [back.stl, tamagotchi.step, tamagotchi_panel.kicad_pcb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]
2024-10-25 optimized animation system
    [tamagotchi_depanelled.kicad_pcb, tamagotchi_panel.kicad_pcb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]
2024-10-25 setting up for tiny wireframes
2024-10-31 trying to get framebuffers working
2024-11-02 a lot!
    okay so gave up on wireframe stuff and instead implemented ageing/hunger. Also added alternate sprites, and started refining the interactivity model
    [Adafruit MicroLipo Charger v2.brd, Adafruit MicroUSB Lipo.brd, Adafruit USB C microlipo charger.brd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]
2025-01-01 reorganizing repo
    [Adafruit MicroLipo Charger v2.brd, Adafruit MicroUSB Lipo.brd, back.stl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]
2025-01-01 added case models
    [back_v0.5.stl, front_v0.5.stl]
2025-05-05 Not sure what i changed!
    New case, new working battery reading code
    [back_v0.5.stl, front.stl, front_v0.5.stl]
2025-05-05 Added switchable sprites
2025-05-09 Optimization
    Refactored some code and added in BUG
    [Tamo.h]
2025-10-01 added font for debugging
    [TOP_SHELL.stl]
2025-10-19 Adding to readme, updating sprites
    [top.stl]
2025-11-17 added in custom ISP programmer files
    [Part Studio 1 - Part 2.stl]
2026-01-23 idek man
    [TOP_SHELL.stl, TOP_SHELL_12.23.25.stl, front.stl]
2026-04-14 big attiny3217 update
    - ported pins, interrupts (not ADC yet)
    - added in FBO support, some new transition animations
    - also! tinyOLED is much smaller than Adafruit GFX+SSD1306, so the project is keeping it and trimming it even more to just what's necessary for tamo
2026-04-18 testing UART, removing PROGMEM
2026-04-22 reorganizing repo structure
    [ISP_Programmer_clip.stl, Part Studio 1 - Part 2.stl]
2026-04-24 fixing upload bugs, tweaking layout of webpage
    [main.cpp, spriteLoader.cpp]
2026-05-16 updating for v1.0 boards
    [BOM_edited_from_jlcpcb.xls, BOTTOM_SHELL_5.7.26.stl, TOP_SHELL_5.7.26.stl]
2026-05-18 testing landing page
2026-05-19 testing landing page again
2026-06-01 designer visual overhaul/semifinal polishing
    not working: dragging frames
2026-08-24 ton of serial bugfixing, some visual updates
    [Display.h, Sprite.cpp, Sprite.h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]
2026-08-26 sprite swap is working!
    [Sprite.h, Tamo.cpp, Tamo.h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]
2026-08-30 readme update
    [BOTTOM_SHELL_5.7.26.stl, bottom.step, top.stl]
